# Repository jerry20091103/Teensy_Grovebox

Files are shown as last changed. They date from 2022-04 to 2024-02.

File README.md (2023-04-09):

# Teensy Grovebox
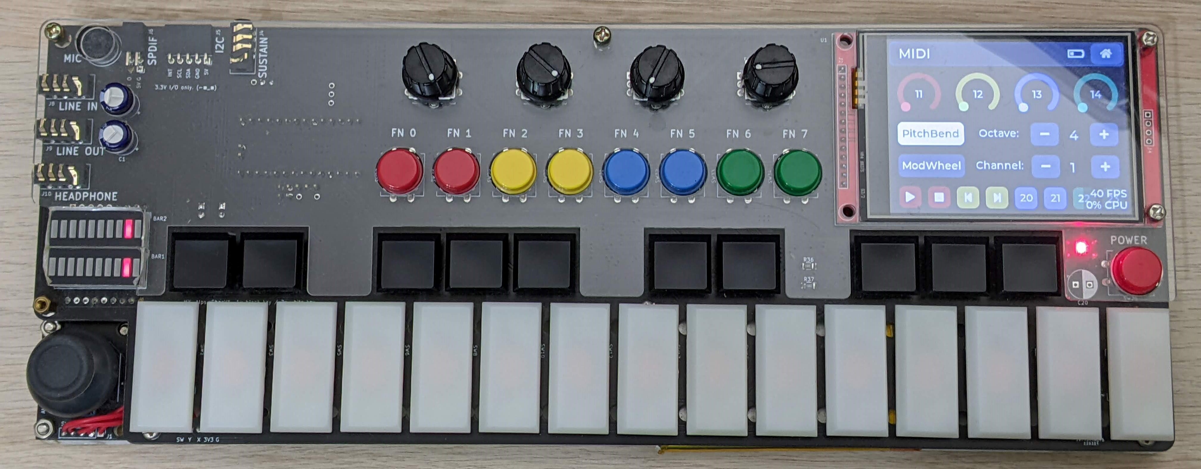
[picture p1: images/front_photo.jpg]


- An all-in-one music multi-tool in a 25-key MIDI keyboard form factor.
- Made with Teensy 4.1 and Teensy Audio Board.
- [Demo video for the synth function.](https://www.youtube.com/watch?v=64bXlY2FwMQ)
- [Demo video for the Sampler function.](https://youtu.be/v5BAqmPcjrQ)
## Hardware Features
- 25-key MIDI keyboard with mechanical key switches.
- 4 encoder knobs and a joystick.
- 3.5 inch TFT touch screen.
- Built-in audio interface with stereo line input/output, and headphone output.
- Onboard speaker and microphone.
- 10+ hours of battery life.
- USB-C charging and data transfer.
- Supports sustain pedal.
- Exposed I2C and S/PDIF headers.
- ...

## Software Features
- USB MIDI keyboard with pitchbend, mod wheel, and 4 assignable knobs.
- Wavetable synth mode to play SF2 soundfonts. (with Teensy SoundFont Decoder ...link)
- Polyphonic synth engine with 8 voices, each with 2 oscillators, 2 LFOs, 3 envelopes, and 1 filter.
- Sampler mode.
- Effects like delay, chorus, reverb... (under development).

## Folders in this repo
> There's a readme file in each folder with more details.
- `Teensy_Grovebox_Hardware`
    - Kicad files for schematic and PCB. 
    - 3D files for the case.
- `Teensy_Grovebox_CODE`
    - Arduino code for the Teensy 4.1.
    - Uses PlatformIO.
- `Joystick_Board`
    - Kicad schematic and PCB files for the joystick board used in the Teensy Grovebox.

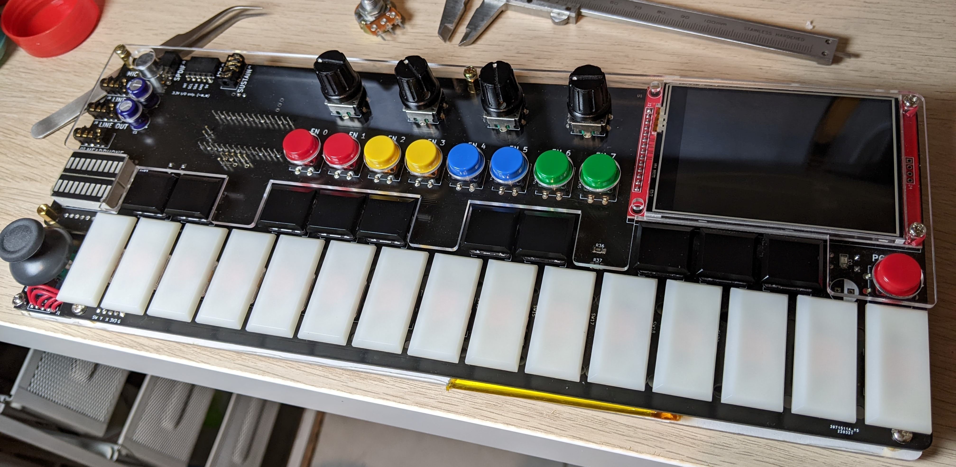
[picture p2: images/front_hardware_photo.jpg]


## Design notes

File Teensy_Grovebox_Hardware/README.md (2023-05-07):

# Teensy Grovebox Hardware
## Overview
- The project is built on the [Teensy platfrom](https://www.pjrc.com/teensy/). Current hardware uses Teensy 4.1 and Teensy Audio Board Rev.D.
## IMPORTANT!
- Two PSRAM chips need to be soldered on the Teensy 4.1 to have max reording time for the sampler. Visit [this PJRC site](https://www.pjrc.com/store/psram.html) for more information.
## Schematic
- `Teensy_Grovebox.kicad_sch`
- Use Kicad 6.

## PCB
- `Teensy_Grovebox.kicad_pcb`
- Use Kicad 6.

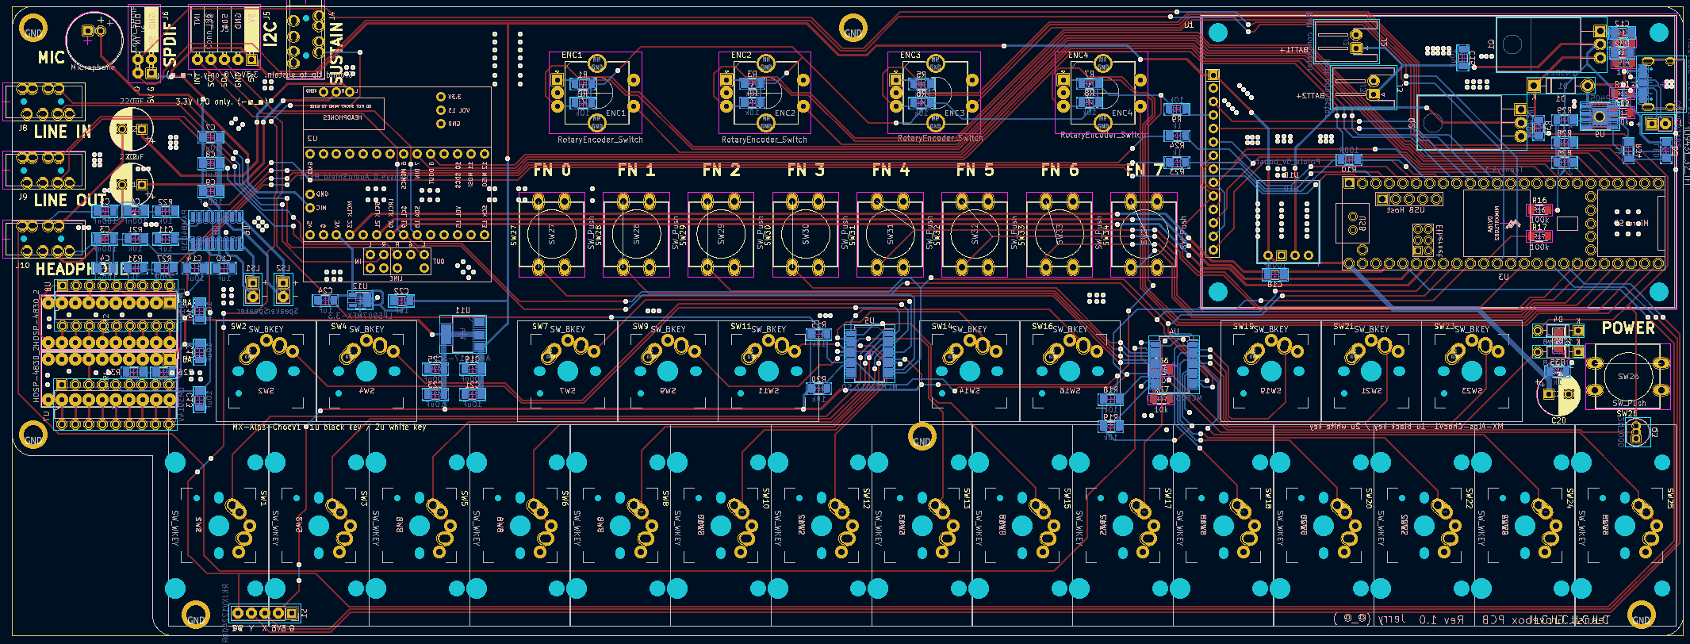
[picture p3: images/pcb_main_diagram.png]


*PCB diagram in Kicad*

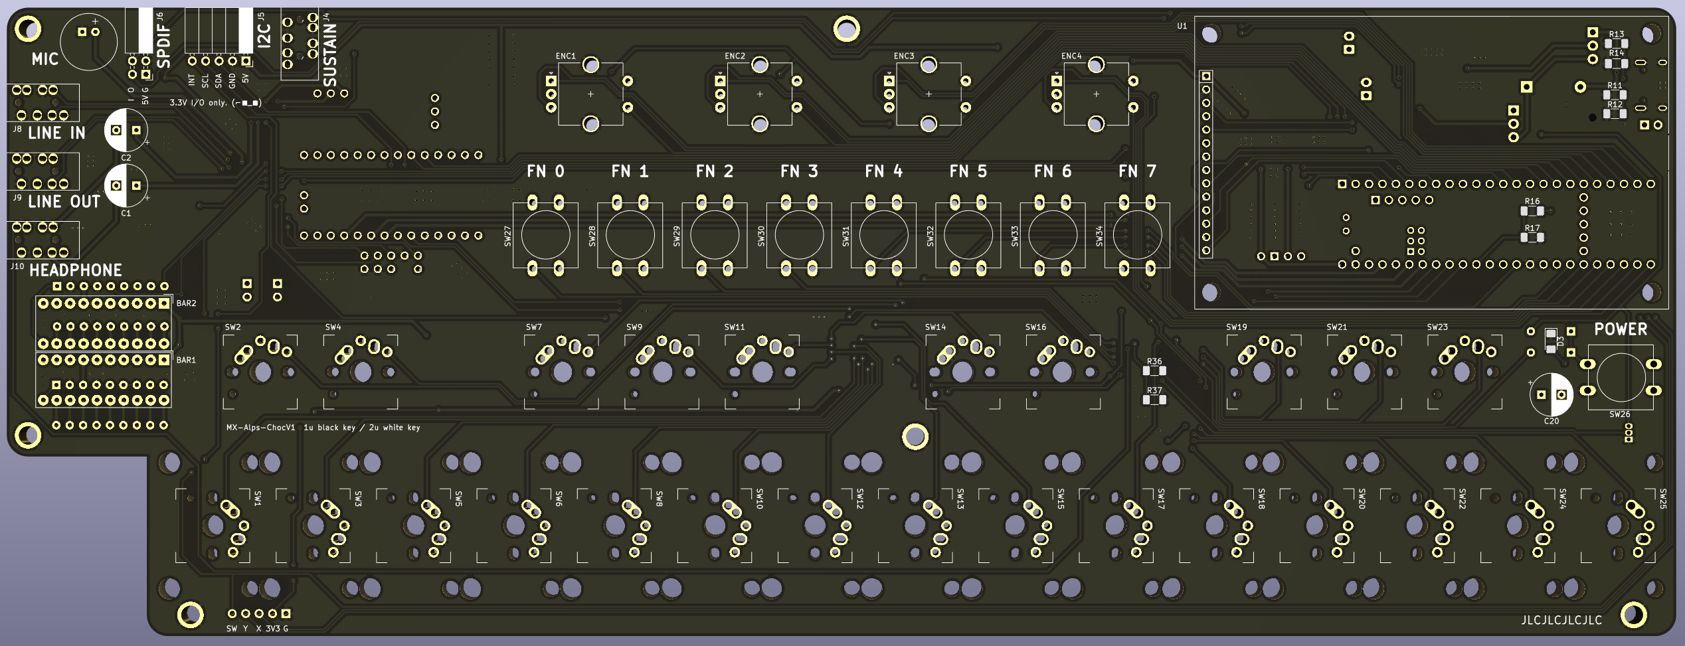
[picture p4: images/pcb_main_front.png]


*Front view of the PCB*

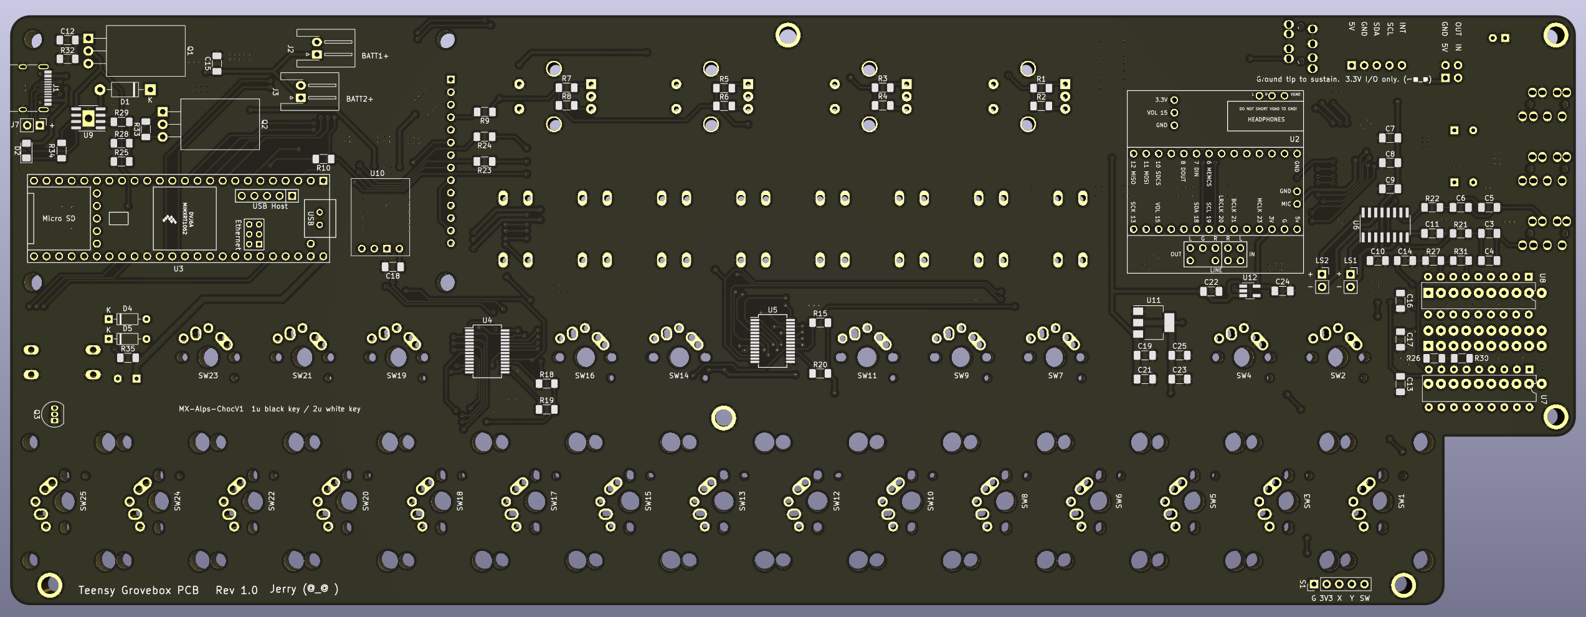
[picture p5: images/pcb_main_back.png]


*Back view of the PCB*

## Case
- Currently we have a simple top and bottom plate as a makeshift case.
- The cutout for the joystick is not correct. You may just omit it.
- A full 3D print enclosure will be available in the future

## Design Details
(TBD)

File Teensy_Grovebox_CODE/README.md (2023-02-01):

# Teensy Grovebox Code
## Overview
- This project uses the PlatformIO development tool.
- The entry point for the program is in `src/main.cpp`
## Dependencies
### Dependencies handled by PlatformIO
- [IoAbstraction](https://github.com/davetcc/IoAbstraction)
    - This library makes it easier to use IO expander pins and Teensy pins together.
- [TaskManagerIO](https://github.com/davetcc/TaskManagerIO)
    - We use this library for scheduling and task management.
### Dependencies in the `lib` folder
- [LVGL - Light and Versatile Embedded Graphics Library](https://lvgl.io/)
    - All GUIs in the project are created with LVGL.
- [ILI9341_T4](https://github.com/vindar/ILI9341_T4)
    - A optimized display driver for the ILI9341 TFT LCD + Teensy4 combo.
## Setup and Build
- Install the PlatformIO extension in Visual Studio Code.
- Open the `Teensy_Grovebox_CODE` folder with Visual Studio Code.
- All the required tools and libraries should be downloaded automatically.
- You can now start to build and program your Teensy.
- > The Arduino VSCode extension may conflict with PlatformIO. You can disable it in your workspace.
## Folders
- `src`
    - All the source files for the project.
    - Each subfolder has related code files.
- `lib`
    - External libraries that are not managed by PlatformIO are here.
- `gui-audio_tool`
    - This is copied from the GUI tool of the  [Teensy Audio Library](https://github.com/PaulStoffregen/Audio)
    - Some custom audio objects for this project are added to the tool.
## Code Structure
(TBD)

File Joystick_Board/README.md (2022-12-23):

# Joystick Board
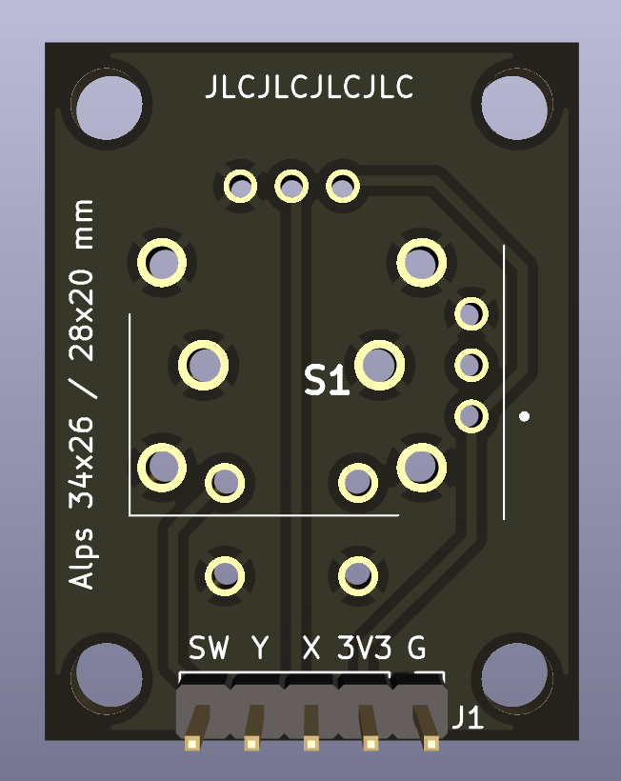
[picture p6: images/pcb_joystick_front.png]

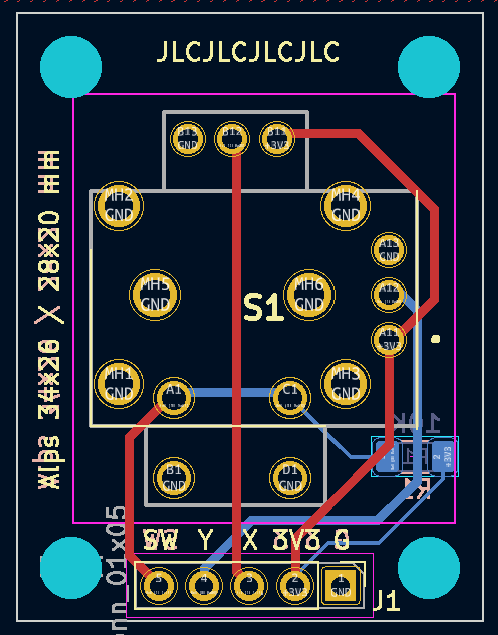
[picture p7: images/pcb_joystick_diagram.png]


## Overview
- This is a simple joystick board that takes standard ALPS joystick modules. (like the ones in PlayStation and Xbox controllers)
- The overall thickness of the Teensy Grovebox would be too thick if the joystick module was mounted on the main PCB. So the joystick board is a separate board that connects to the Teensy Grovebox PCB.
## Contents
- Kicad files and Gerber outputs for the joystick board.

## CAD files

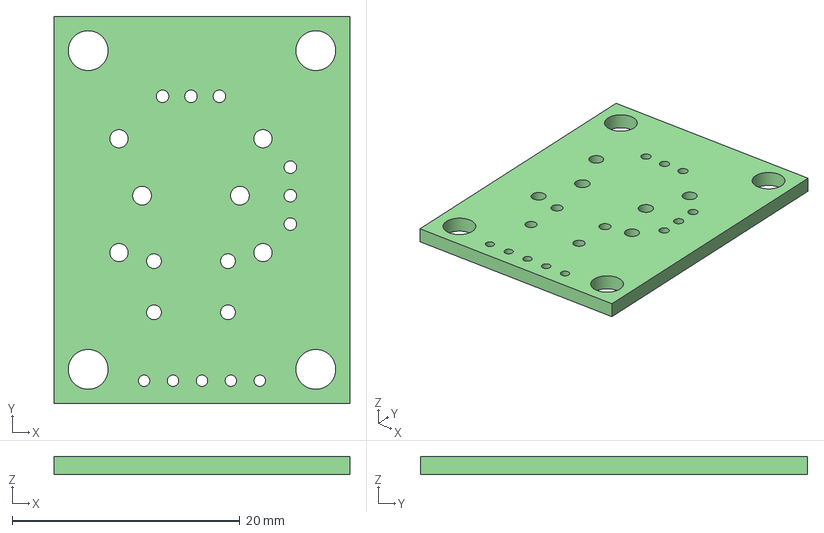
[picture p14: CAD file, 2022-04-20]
Joystick_Board/Joystick_Board.step
26.0 x 34.0 x 1.60 mm

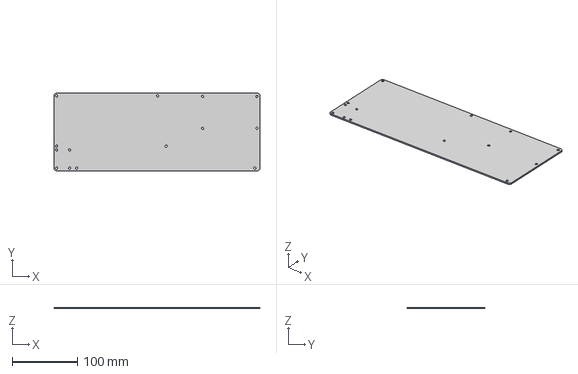
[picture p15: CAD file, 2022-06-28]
Teensy_Grovebox_Hardware/Bottom_Plate.step
316.0 x 119.0 x 2.00 mm

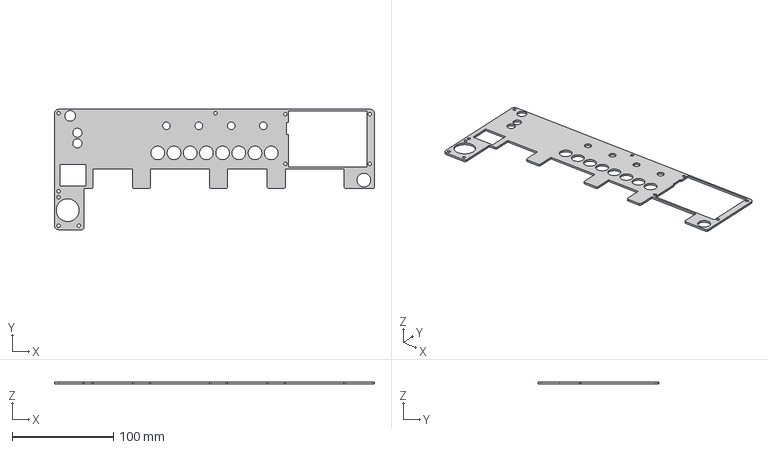
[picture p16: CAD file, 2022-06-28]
Teensy_Grovebox_Hardware/Top_Plate.step
316.0 x 119.0 x 2.00 mm

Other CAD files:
Teensy_Grovebox_Hardware/bottom_plate.dxf
Teensy_Grovebox_Hardware/top_plate.dxf

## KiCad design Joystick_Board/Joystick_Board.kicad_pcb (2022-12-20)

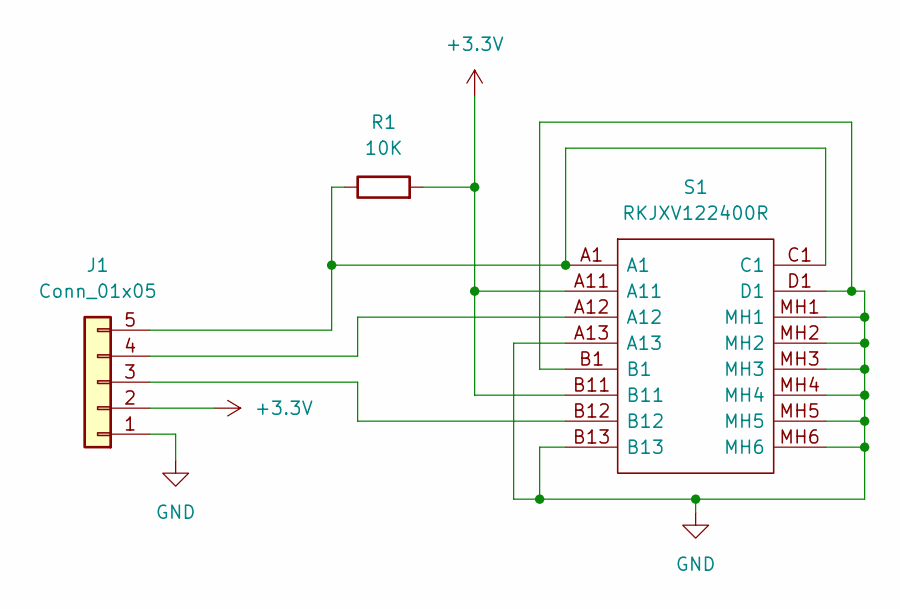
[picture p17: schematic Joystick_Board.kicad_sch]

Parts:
J1: Conn_01x05; PinHeader_1x05_P2.54mm_Vertical
R1: 10K; R_1206_3216Metric_Pad1.30x1.75mm_HandSolder
S1: RKJXV122400R; Mouser Part Number 688-RKJXV122400R

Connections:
+3V3: J1.2, R1.2, S1.A11, S1.B11
GND: J1.1, S1.A13, S1.B1, S1.B13, S1.D1, S1.MH1, S1.MH2, S1.MH3, S1.MH4, S1.MH5, S1.MH6
unnamed: J1.3, S1.B12
unnamed: J1.4, S1.A12
unnamed: J1.5, R1.1, S1.A1, S1.C1

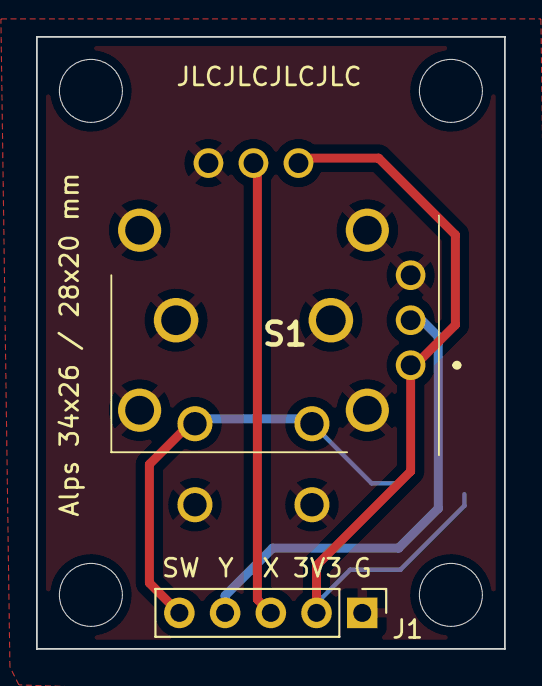
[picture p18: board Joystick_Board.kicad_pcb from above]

Board: 2 copper layers, 26.0 x 34.0 mm, 4 parts (1 on the bottom side), 5 nets.

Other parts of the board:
U4: HOLE; MountingHole

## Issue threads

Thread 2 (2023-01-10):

A few questions around hardware

lucas14145, 2023-01-10:
Hi, thanks for sharing all that work. This project looks really cool.

I was wondering before I order all the parts:
Is it the final version of the pcb?
What pololu 5v booster are you using?
What about this capacitor next to the power button, no need for it?

I hope this is the right place to ask questions.

jerry20091103, 2023-01-11:
Thanks for being interested in this project!

The PCB works fine. It will function just like in the video.
The 5v booster is U1V11F5 from Pololu. But any 3~5v to 5v 1A boost converter should work.
That capacitor is optional. Omitting it should not affect anything. The placement is awkward too...(It blocks the key)

However, the hardware is first-gen and there are some known issues:
- Some parts are a pain to solder (the type c connector, IO expander chip...)
- The boost converter does not have enough juice for the built-in speaker amp. So the audio distorts at high volume. (other outputs are fine though.)
- The power button is extremely easy to get at. It may turn itself on in a backpack.
- The two LED bars on the left are currently unused and will be removed in later versions.
- There's no place to properly mount the built-in speaker.
- The 3.5mm jacks are a little hard to find.
- There's a "pop" noise in the headphone output at startup.

I'm currently focusing on the software, as there are lots of features yet to be implemented. Once all the major features I wanted are finished, I can move on to hardware improvements. I think it will come no earlier than this summer...

I would really appreciate it if you build it and share feedback (or even add features) with me though.

lucas14145, 2023-01-11:
Thanks for your answer, I'm looking forward for updated on this project.
Yes I will definitely let you know if I build it.
For those two led bars they looked super cool but not so easy to source and expensive plus it save quite a lot of soldering anyway.
I see no batterie protection IC on the circuit is it on purpose? I have not much knowledge on electronic but I remember using one on a small batterie embedded project that I made...

jerry20091103, 2023-01-11:
I use Li-po batteries with protection boards built-in.
They are quite common, like this one [https://www.adafruit.com/product/258](https://www.adafruit.com/product/258)
The small PCB on the top is the protection circuit.
This is probably safer than implementing a protection circuit myself... ;)

VilhoKn, 2023-03-14:
Hi, I really like the whole design but had couple questions about it.

What speaker are you using?
Have you thought about any solutions for the speaker amp distorting? (having a speaker is important for me)
How are the usb D- and D+ connected to the teensy?

I'm a beginner and don't have a lot of experience with electronics but hope to learn more.

jerry20091103, 2023-03-15:
Hi,
- One quick fix for the speaker distortion problem is to swap out the Pololu U1V11F5 5V booster for a higher current one. I do plan to upgrade the amp chip, but that would hopefully happen in the next hardware revision.
- Any 4-ohms speaker with at least a 3W power rating should work fine. Choose one that fits in the enclosure.
- The Teensy does not have pin headers for USB. It uses small solder pads right under the USB port. Solder two wires from the pads to J7 on the PCB,  to connect D- and D+.

Thanks for being interested in this project!

lucas14145, 2023-05-05:
Hi Jerry,
I'm slowly gathering the components to make one for myself!
Right now I have the teensy 4.1 and the audio shield , the screen is on it's way. I choose to use the Gateron ks-33 low profile as mechanical switch and some modification to the footprint has to be done on Kicad. I removed the led bars and there controllers as you said it won't be used on the final design. That leaves the pin 4 and 5 on the teensy free ( RGB the keys? not sure how that would implement in your code and if I will bother soldering all those tiny ws2812 led )
I was thinking about using the nintendo switch joystick. As it is more compact, no need to have a separate board for it, I think.

Is there anything you would change, add. If you plan to release a new board version soon I will wait but I was thinking that would be a nice device to have for the summer!

jerry20091103, 2023-05-07:
Hi Lucas,
Removing the LED bars leaves pins 3, 4, and 5 free. I thought about the RGB keys, but ultimately removed them due to increased power consumption and cost. You may add them if you want though. It should not be hard to run the led library within the code.

I actually put Nintendo Switch joysticks in the original design, but I prefer the longer travel of normal joysticks. It's just a personal preference.

I do plan to make a new hardware version. But it won't come maybe until at least late August... (I'm still a busy CS student...)
In the new version, most functionality will stay the same. I am hoping to address the issues mentioned in the above posts, and also make it easier to put together too.
Currently, some SMT components are really hard to solder. I plan to make it compatible with SMT assembly services like JLCPCB, so people can skip them and just solder the easy through-hole parts. Also, use more common 3.5 jacks, boost converts, and 18650 batteries...

If you still want to build the current version, I would suggest using pin sockets to secure the teensy and audio board, so you can
easily reuse them later at the sacrifice of some extra thickness.

jerry20091103, 2023-05-25:
Hi, Lucas,
The connectors for SPDIF and I2C are generic 2.54mm pin sockets. They are very common, and you don't even need to solder them if you don't use them. I use them to connect stuff on a breadboard. I remember the power draw is 200~500 mA at 5V depending on the screen brightness and volume.

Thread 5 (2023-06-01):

License?

Merlin04, 2023-06-01:
I'm building a similar teensy-based synthesizer and it would be great if I could include some of your code - could you put it under an open source license to make this possible?

jerry20091103, 2023-06-03:
Hello,
Feel free to use the code in your projects. I've created a license file and this project is under MIT license.
Please let me know if you happen to find any bugs in the code.

Closed 2023-06-28.

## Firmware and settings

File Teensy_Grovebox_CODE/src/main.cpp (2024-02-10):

#ifdef DEBUG
#pragma GCC optimize ("O0")
#endif

#include "Hardware.h"
#include "font_Arial.h"
#include "Controls.h"
#include "Pages/Pages.h"
#include "Audio/AudioObjects.h"
#include "Audio/AudioIO.h"
#include "Audio/AudioSynth.h"

#ifdef DEBUG
#include "TeensyDebug.h"
#endif

int bar_test;
int batt_level;
unsigned long lastBarUpdate;

void updateSynthModulation()
{
    AudioSynth.updateModulation();
}

void updateGui()
{
    lv_timer_handler();
}

void updatePage()
{
    PageManager.PageArr[PageManager.getCurPage()]->update();
}

extern float tempmonGetTemp(void);

void checkAudioUsage()
{
    Serial.println("=======================");
    Serial.println("Audio Memory:  " + String(AudioMemoryUsageMax()));
    Serial.println("Audio CPU:     " + String(AudioProcessorUsageMax()) + " %");
    Serial.println("CPU Temp:      " + String(tempmonGetTemp()) + " C");
    AudioMemoryUsageMaxReset();
    AudioProcessorUsageMaxReset();

    lv_mem_monitor_t mon;
    lv_mem_monitor(&mon);
    Serial.println("lvgl mem free: " + String(mon.free_size) + " B");
    Serial.println("lvgl mem used: " + String(mon.used_pct) + " %");
    Serial.println("lvgl mem frag: " + String(mon.frag_pct) + " %");
}

void readKeyVeloctiy()
{
    // get velocity from microphone
    AudioSynth.velocity = peakVelocity.read();
}

PROGMEM
void setup()
{
    // mute amp
    pinMode(0, OUTPUT);
    digitalWrite(0, LOW);

#ifdef DEBUG
    /*
    Somehow if we comment out the reset_PFD() on line 101 of cores/teensy4/startup.c, the debugging works.
    */
    while (!SerialUSB1) {}
    debug.begin(SerialUSB1);
    halt_cpu();
#endif
    Serial.begin(9600);
#if LV_USE_LOG != 0
    while (!Serial)
         ; // wait for Arduino Serial Monitor
#endif
    Serial.println("Setup begin!");

    digitalWrite(BAR_MODE, HIGH);
    bar_test = 10;

    batt_level = analogRead(BATT_LVL);

    // Audio connections require memory to work.  For more
    // detailed information, see the MemoryAndCpuUsage example
    AudioMemory(200);

    // Enable the audio shield, select input, and enable output
    sgtl5000_1.enable();
    sgtl5000_1.inputSelect(AUDIO_INPUT_LINEIN);
    sgtl5000_1.unmuteLineout();

    // Initialize hardware
    HardwareSetup();
    // set GUI data and switch to first page
    PageManager.loadAll();
    PageManager.switchPage(PG_HOME);
    // Schedule regular tasks
    taskManager.scheduleFixedRate(3, updateSynthModulation);
    taskManager.scheduleFixedRate(5, updateGui);
    taskManager.scheduleFixedRate(30, updatePage);
    taskManager.scheduleFixedRate(10, UpdateJoystick);
    taskManager.scheduleFixedRate(15, readKeyVeloctiy);

    // unmute amp
    digitalWrite(0, HIGH);
    // Change BAR PWM frequencey
    analogWriteFrequency(BAR1_OUT, 10000);
    analogWriteFrequency(BAR2_OUT, 10000);

    // DEBUG
    taskManager.scheduleFixedRate(5000, checkAudioUsage);
}

void loop(void)
{
    // unsigned long curTime = millis();
    // if (curTime - lastBarUpdate > 1000)
    // {
    //     batt_level = analogRead(BATT_LVL);
    //     bar_test += 20;
    //     if (bar_test > 210)
    //         bar_test = 10;
    //     analogWrite(BAR1_OUT, bar_test);
    //     analogWrite(BAR2_OUT, bar_test);
    //     lastBarUpdate = curTime;
    // }
    taskManager.runLoop();
}

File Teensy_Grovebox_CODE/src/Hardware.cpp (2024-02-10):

#include "Hardware.h"
#include "Controls.h"
#include "Pages/Pages.h"
#include "misc/lv_log.h"

// 2 diff buffers for the LCD
DMAMEM ILI9341_T4::DiffBuffStatic<8000> tft_diff1;
DMAMEM ILI9341_T4::DiffBuffStatic<8000> tft_diff2;

// Display driver object
ILI9341_T4::ILI9341Driver tft(TFT_CS, TFT_DC, TFT_SCK, TFT_MOSI, TFT_MISO, TFT_RST, TFT_TOUCH_CS, TFT_TOUCH_IRQ);

IntervalTimer guiTimer;

// internal frame buffer for the LCD driver
DMAMEM uint16_t tft_fb[TFT_X * TFT_Y];

// lvgl draw buffer
DMAMEM lv_color_t lvgl_buf[TFT_X * 40];

lv_disp_draw_buf_t draw_buf; // lvgl 'draw buffer' object
lv_disp_drv_t disp_drv;      // lvgl 'display driver'
lv_indev_drv_t indev_drv;    // lvgl 'input device driver'

MultiIoAbstractionRef multiIo = multiIoExpander(EXPANDER_PIN);

HardwareRotaryEncoder *enc[4];


#if LV_USE_LOG != 0
/* LVGL Serial debugging */
void my_print(const char * buf)
{
    Serial.printf(buf);
    Serial.flush();
}
#endif

/** Callback to draw on the screen */
void myDispFlush(lv_disp_drv_t *disp, const lv_area_t *area, lv_color_t *color_p)
{
    const bool redraw_now = lv_disp_flush_is_last(disp);                                       // check if when should update the screen (or just buffer the changes).
    tft.updateRegion(redraw_now, (uint16_t *)color_p, area->x1, area->x2, area->y1, area->y2); // update the interval framebuffer and then redraw the screen if requested
    lv_disp_flush_ready(disp);                                                                 // tell lvgl that we are done and that the lvgl draw buffer can be reused immediately
}

/** Call back to read the touchpad */
void myTouchRead(lv_indev_drv_t *indev_driver, lv_indev_data_t *data)
{
    int touchX, touchY, touchZ;
    static int lastX = 0, lastY = 0;
    bool touched = tft.readTouch(touchX, touchY, touchZ); // read the touchpad
    if (!touched)
    { // nothing
        data->state = LV_INDEV_STATE_REL;
    }
    else
    { // pressed
        data->state = LV_INDEV_STATE_PR;
        // if the touch is too close to the last one, running average 4 of them to reduce jitter
        if (abs(touchX - lastX) < 10 && abs(touchY - lastY) < 10)
        {
            touchX = (touchX + lastX * 3) / 4;
            touchY = (touchY + lastY * 3) / 4;
        }
        lastX = touchX;
        lastY = touchY;
        data->point.x = touchX;
        data->point.y = touchY;
    }
}

// callback to update lvgl's tick every ms.
void guiInc()
{
    lv_tick_inc(1);
}

void HardwareSetup()
{
    // Setup LCD
    tft.begin(SPI_SPEED);
    tft.setFramebuffer(tft_fb);
    tft.setDiffBuffers(&tft_diff1, &tft_diff2);
    tft.setRotation(3);
    tft.setDiffGap(4);
    tft.setVSyncSpacing(1);
    tft.setRefreshRate(80);
    // LCD brightness control
    pinMode(TFT_BACKLIGHT, OUTPUT);
    analogWrite(TFT_BACKLIGHT, 200);

    // LCD touch calibration
    //tft.calibrateTouch();
    int touchCalib[4] = {371, 3817, 3926, 495};
    tft.setTouchCalibration(touchCalib);

    // Setup LVGL
    lv_init();
#if LV_USE_LOG != 0
    lv_log_register_print_cb(my_print); /* register print function for debugging */
#endif
    lv_disp_draw_buf_init(&draw_buf, lvgl_buf, NULL, TFT_X * TFT_Y_BUF);
    lv_disp_drv_init(&disp_drv);
    disp_drv.hor_res = TFT_X;
    disp_drv.ver_res = TFT_Y;
    disp_drv.flush_cb = myDispFlush;
    disp_drv.draw_buf = &draw_buf;
    lv_disp_drv_register(&disp_drv);

    // Setup LVGL input device driver
    lv_indev_drv_init(&indev_drv);
    indev_drv.type = LV_INDEV_TYPE_POINTER;
    indev_drv.read_cb = myTouchRead;
    lv_indev_drv_register(&indev_drv);

    // Initializes GUI
    PageManager.Init();

    // setup io expanders
    Wire.begin();
    Wire.setClock(400000);
    multiIoAddExpander(multiIo, ioFrom23017(0x20, ACTIVE_LOW_OPEN, 17), 16);
    multiIoAddExpander(multiIo, ioFrom23017(0x21, ACTIVE_LOW_OPEN, 17), 16);
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

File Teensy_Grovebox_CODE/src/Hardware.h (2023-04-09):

#ifndef HARDWARE_H
#define HARDWARE_H

#include "SPI.h"
#include "ILI9341_T4.h"
#include "lvgl.h"
#include "IoAbstractionWire.h"
#include "TaskManagerIO.h"
#include "ExecWithParameter.h"

// *Pins
// LCD
#define TFT_MOSI 11
#define TFT_MISO 12
#define TFT_SCK 13
#define TFT_DC 9
#define TFT_CS 10
#define TFT_RST 255
#define TFT_BACKLIGHT 6
#define TFT_X 320
#define TFT_Y 240
// Touch display
#define TFT_TOUCH_CS 5
#define TFT_TOUCH_IRQ 4
// SPI (used for lcd and touch)
#define SPI_SPEED 60000000
// Expanders
#define EXPANDER_PIN 100        // The expander pins starts at 100
#define EXPANDER2_PIN 116
#define E1GPA(a) (EXPANDER_PIN + a)         // These converts expander pin numbers to IO pin numbers
#define E1GPB(b) (EXPANDER_PIN + b + 8)     // for the IoAbstraction library
#define E2GPA(a) (EXPANDER2_PIN + a)
#define E2GPB(b) (EXPANDER2_PIN + b + 8)
// Rotray Encoders
#define ENC1A 26
#define ENC1B 25
#define BTN_ENC1 24
#define ENC2A 29
#define ENC2B 28
#define BTN_ENC2 27
#define ENC3A 32
#define ENC3B 31
#define BTN_ENC3 30
#define ENC4A 35
#define ENC4B 34
#define BTN_ENC4 33
// Joysitck
#define JOY_X 41
#define JOY_Y 40
#define BTN_JOY 22
// Misc.
#define AMP_SHDN 0
#define BAR1_OUT 2
#define BAR2_OUT 3
#define BAR_MODE 1
#define BATT_LVL 16
#define HP_DETECT E2GPA(5)
#define BTN_PWR E2GPA(6)
#define PWR_HOLD E2GPA(7)
// FN Keys
#define BTN_FN0 E2GPA(1)
#define BTN_FN1 E2GPA(2)
#define BTN_FN2 E2GPA(3)
#define BTN_FN3 E2GPA(4)
#define BTN_FN4 39
#define BTN_FN5 38
#define BTN_FN6 37
#define BTN_FN7 36
// Piano Keys
#define BTN_K1 E1GPB(0)
#define BTN_K2 E1GPB(1)
#define BTN_K3 E1GPB(2)
#define BTN_K4 E1GPB(3)
#define BTN_K5 E1GPB(4)
#define BTN_K6 E1GPB(5)
#define BTN_K7 E1GPB(6)
#define BTN_K8 E1GPB(7)

#define BTN_K9 E1GPA(0)
#define BTN_K10 E1GPA(1)
#define BTN_K11 E1GPA(2)
#define BTN_K12 E1GPA(3)
#define BTN_K13 E1GPA(4)
#define BTN_K14 E1GPA(5)
#define BTN_K15 E1GPA(6)
#define BTN_K16 E1GPA(7)

#define BTN_K17 E2GPB(0)
#define BTN_K18 E2GPB(1)
#define BTN_K19 E2GPB(2)
#define BTN_K20 E2GPB(3)
#define BTN_K21 E2GPB(4)
#define BTN_K22 E2GPB(5)
#define BTN_K23 E2GPB(6)
#define BTN_K24 E2GPB(7)

#define BTN_K25 E2GPA(0)

// Display driver object
extern ILI9341_T4::ILI9341Driver tft;

// lvgl draw buffer
#define TFT_Y_BUF 40

// IO abstraction object
extern MultiIoAbstractionRef multiIo;

// encoder objects
extern HardwareRotaryEncoder* enc[4];

PROGMEM void HardwareSetup();

#endif

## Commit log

2022-05-01 Add power off prompt. Fix bugs in Midi page.
    [Hardware.cpp, Hardware.h, MidiPage.cpp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]
2022-06-02 Add velocity detection with microphone.
2022-06-28 Add sf2 select list box.
    [Bottom_Plate.step, Top_Plate.step]
2022-07-08 Add sound font switching.
2022-07-11 PCB bug fix.
2022-07-21 Add noise generator in synth.
    [AudioSynth.cpp, SynthPage.cpp]
2022-07-29 Add ladder filter to synth
2022-08-03 Add modified teensy audio gui tool to the repo.
2022-12-19 Folder organization.
    [Bottom_Plate.step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]
2022-12-20 Add images to readmes.
    [Joystick_Board.kicad_pcb]
2023-01-11 Include 5v booster model number in PCB files.
    [Teensy_Grovebox.kicad_sch]
2023-01-31 Bug fix in AudioSynth. Turn off OSCs when not in synth mode.
    [AudioSynth.cpp]
2023-02-02 Fix bugs in AudioSynth.
    [AudioSynth.cpp]
2023-02-03 Half done SampleEditorPage.
2023-02-04 Finished SampleEditorPage.
2023-02-04 Add loop crossfade and level meter / polish, in SampleEditorPage.
2023-02-05 Add Gui_Spinbox. Replace multiple objects with spinbox.
    [MidiPage.cpp, MidiPage.h, SynthPage.cpp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]
2023-02-08 Finished sampler function in AudioSynth.
2023-02-12 Found bugs in pitchbend of wavetable synth mode.
    [AudioSynth.cpp, SynthPage.cpp, WaveTablePage.cpp]
2023-02-28 Finished basic Sampler UI.
2023-03-01 Add root key selection in sampler.
2023-03-04 Fix wrong title in envelope arc.
    [SynthPage.cpp]
2023-03-04 Reduce touch input jitter.
    [Hardware.cpp]
2023-03-05 Remove biquad in sampler; minor update in UI.
2023-03-05 Add basic pitchbend to sampler.
2024-01-18 Add debugger support (not working properly)
    [main.cpp]
2024-01-18 Add new GUI objects to replace old code.
    [ParamArc.cpp, Spinbox.cpp]
2024-01-19 Fix ccArc not set to NULL after delete
    [MidiPage.cpp]
2024-01-20 Remove serial prints; fix include error in AudioUtility; remove useless code.
    [MidiPage.cpp, ParamArc.cpp]
2024-01-21 Fix bugs in Buttons and VolumeBar
2024-01-21 Port SampleEditorPage to new dynamic GUI.
2024-02-06 Fix bug in Button. Hold callback does not handle reverse checked state correctly.
2024-02-06 Add support for non zero starting value for ParamArc. The offset is handled automatically. Also Add checks before calling from binded encoders.
2024-02-09 Reduce LV_MEM_SIZE in lv_conf.h from 64k to 48k. Fix not unloading in loadAll(). Minor fix in AudioPage.
    [AudioPage.cpp]
2024-02-10 Move modList from the audio system to GUI. Modulation subpage now loads mod entries correctly.
    [AudioSynth.cpp, SynthPage.cpp]
